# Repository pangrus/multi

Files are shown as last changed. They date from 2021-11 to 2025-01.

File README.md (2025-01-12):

## multi

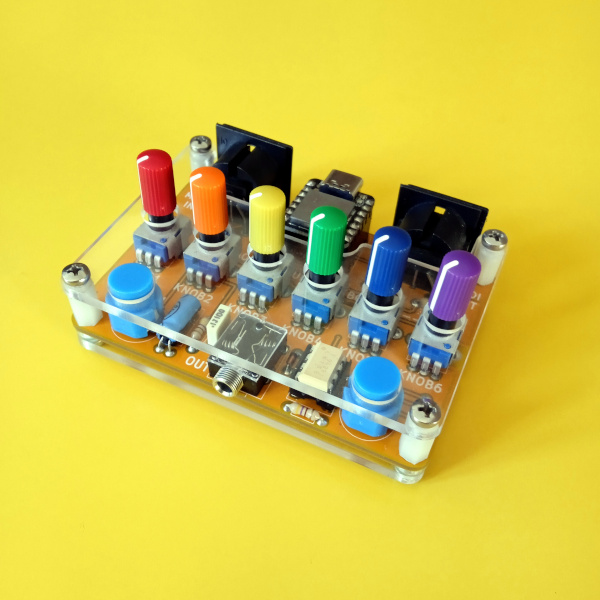
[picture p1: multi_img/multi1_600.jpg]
multi


**What is multi?**  
**multi** is an open hardware circuit board hosting a [Seeeduino XIAO](https://wiki.seeedstudio.com/Seeeduino-XIAO/), 6 pots, 2 pushbuttons, 2 Midi DIN connectors and an audio output.   
The Seeeduino XIAO board carries the powerful ATSAMD21G18A-MU which is a low-power microcontroller and has 14 GPIO PINs, a DAC output and one UART interface. To avoid grounding loops the MIDI input is properly opto-isolated, as required by official specifications.    

**Bend multi to your needs**  
The strong point is that you can program your **multi** as you need, using the Arduino IDE. 
On the MIDI side, possible use includes advanced midi controlling, filtering and remapping as well as algorithmic arpeggiators and aleatoric patch generators. It's also perfect to explore digital synthesis techniques. 

**Sound generation**    
Since the Xiao board has a DAC, **multi** can also be used to produce sounds using the [Mozzi sonification library](https://github.com/sensorium/Mozzi) written by Tim Barrass or accessing directly to the DAC output.
 
**Software**    
 There are already several usable software and the list is constantly expanding:    

- **synth sequencer** three oscillators monophonic synth with embedded sequencer. It receives MIDI clock and note messages
- **drone** it's a six oscillators drone machine   
- **euclidean sequencer** receives midi clock, start/stop on the MIDI DIN input, generates euclidean rhythmes on the MIDI DIN output
- **bytebeat player** allows to play algorithmic music with no instruments and no real oscillators but a math expression that creates an audio output waveform as a function of time, processed 8000 times per second. The expression has six parameters accessible through the **multi** knobs
- **fourier** 3 voices drone generator, each voice is composed by six oscillators tuned on the harmonic overtones, each voice has six lfos
- **cc scrambler** generates random synthesizer patch by spitting out random MIDI CC values (preset fucker)    
- **multimode** keep pressed PB1 and PB2 to choose the mode between: synth sequencer, drone, euclidean sequencer, bytebeat player, fourier and cc scrambler 
- **midi converter** is a USB to 5 DIN bi-directional MIDI converter    
- **midi metronome** takes the MIDI clock from the 5 DIN midi connector and generates a metronome click on the audio output, to allow acoustic musicians to synchronize their performance to an electronic setup     
- **hardware test** if you have choosen the DIY kit you may want to use this software to test your build    
- **fm** a simple fm synth    
- **blink** the ubiquitous blink sketch    

**Compiling and uploading**  
Install the [Arduino IDE](https://www.arduino.cc/en/software), last version tested is 2.3.4.  
Add the Seeeduino Xiao board to your Arduino IDE. Follow the [instructions to get started](https://wiki.seeedstudio.com/Seeeduino-XIAO/#software) on the SeeedStudio wiki and install the version 1.7.8 of the _Seeed SAMD Boards_ package.  
To compile the software, you'll need some libraries, install them from the Arduino IDE Library Manager:  
- [Mozzi](https://github.com/sensorium/Mozzi), tested with version 2.0.1, also install library dependencies
- [Adafruit TinyUSB Library](https://github.com/adafruit/Adafruit_TinyUSB_Arduino), tested with version 0.10.5, no dependencies needed
- [MIDI Library](https://github.com/FortySevenEffects/arduino_midi_library), tested with version 5.0.2  

From the Arduino IDE Tools menu, select _TinyUSB_ as USB stack.

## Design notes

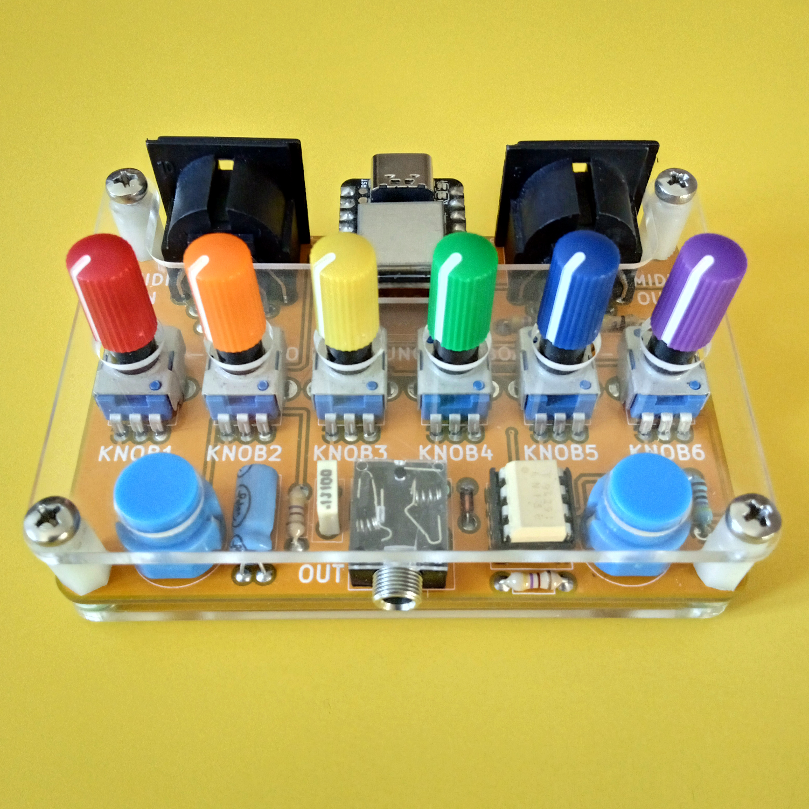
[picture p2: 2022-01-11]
multi_img/multi2.jpg

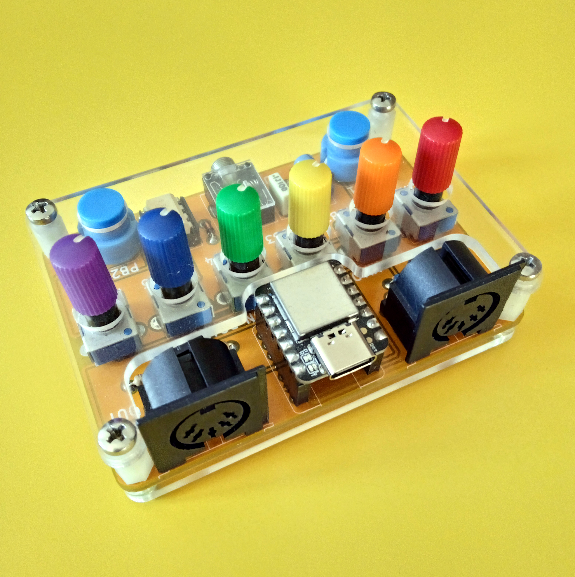
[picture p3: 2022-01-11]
multi_img/multi3.jpg

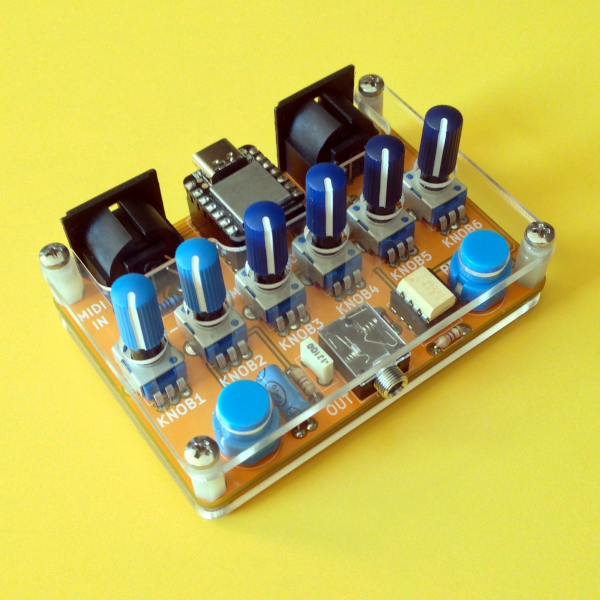
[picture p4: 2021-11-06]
multi_img/multi600.png

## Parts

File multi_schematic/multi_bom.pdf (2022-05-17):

multi - bill of materials

C1 | 100nF | 100V 5% Polyester Capacitor
C2 | 1uF | 50V 105C Radial Electrolytic Capacitor
D1 | 1N4148 | 100V 0.15A standard switching diode
J1 | MIDI IN | 5-pin DIN connector
J2 | MIDI OUT | 5-pin DIN connector
J3 | OUT | 3.5mm Stereo Audio Jack
KNOB 1-6 | 10K | Potentiometer Song Huei RK0904N
PB1,PB2 | Pushbutton | C&K D6R60
R1, R6 | 470 Ohm | Resistor 1/4W
R2, R3 | 47 Ohm | Resistor 1/4W
R4 | 220Ohm | Resistor 1/4W
R5 | 4,7kOhm | Resistor 1/4W
U1 | 6N138 | Low Input Current Optocoupler (8 pin IC socket)
U2 | XIAO | Seeeduino XIAO (7 pin female header x2)

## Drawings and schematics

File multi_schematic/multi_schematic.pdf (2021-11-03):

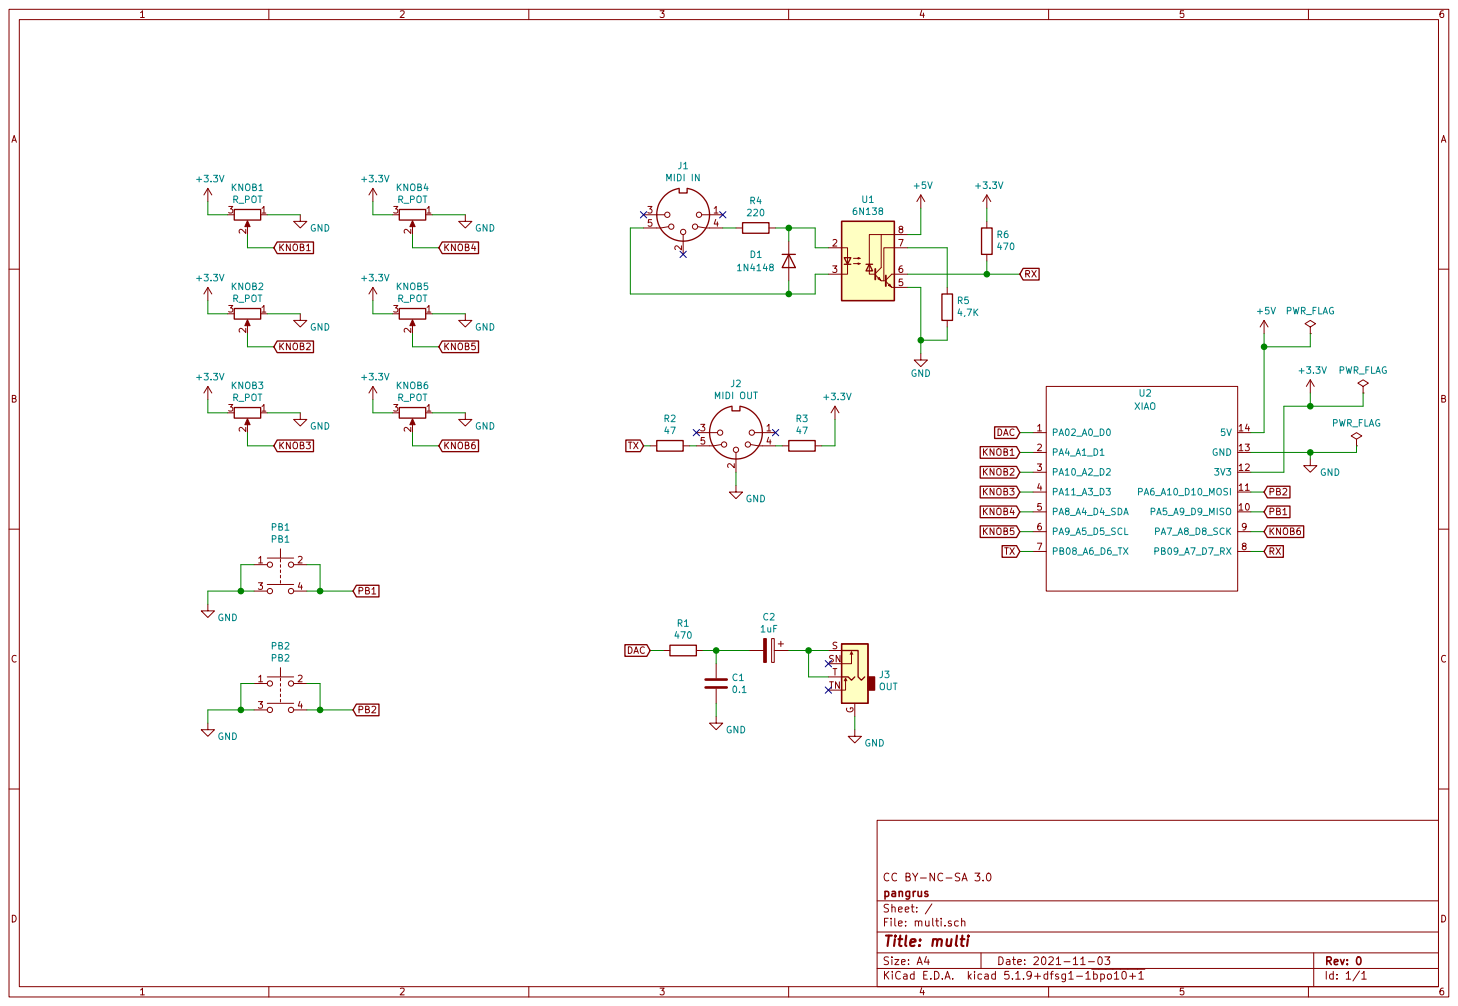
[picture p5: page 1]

Id: 1/1 Title: multi File: multi.sch Sheet: / pangrus CC BY-NC-SA 3.0

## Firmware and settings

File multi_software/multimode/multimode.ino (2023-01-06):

/*
                   _ _   _                     _
   _ __ ___  _   _| | |_(_)_ __ ___   ___   __| | ___
  | '_ ` _ \| | | | | __| | '_ ` _ \ / _ \ / _` |/ _ \
  | | | | | | |_| | | |_| | | | | | | (_) | (_| |  __/
  |_| |_| |_|\__,_|_|\__|_|_| |_| |_|\___/ \__,_|\___|

  multimode v2.2
  CC BY-NC-SA pangrus 2022
  ------------------------

  knobs 1 to 6 are used to select the mode at power up
  knobs 1 to 6 are sending MIDI CC on USB and DIN connectors

  select mode:
  ------------
  set all the knobs fully CCW
  select mode by setting only one knob fully CW (KNOB1 -> mode 1...)
  keep pressed PB1 and PB2 for 4 seconds

  mode 1 : synth sequencer
  ------------------------
  knob1         synth release
  knob2         synth cutoff
  knob3         synth resonance and detune, step advance amount
  knob4         selects sequence
  knob5         transpose sequence
  knob6         sequencer tempo

  mode 2 : drone
  6 oscillators drone generator with 6 lfos
  -----------------------------------------
  knobs 1 to 6  controls the oscillators frequency
  pb1 switches  drone on/off
  pb2 switches  lfos on/off

  mode 3 : euclidean drum sequencer
  ----------------------------
  receives midi clock, start/stop on the MIDI DIN input
  generates euclidean rhythmes on the MIDI DIN output
  knob 1,2,3 selects number of beats to be played
  knob 4,5,6 pattern length
  pb1 randomize pattern 2
  pb2 randomize pattern 3

  mode 4: bytebeat player
  -----------------------
  knobs are affecting expression parameters
  pb1 and pb2 selects different expressions

  mode 5: fourier (3 voices drone generator)
  ------------------------------------------
  each voice is composed by six oscillators tuned on the harmonic overtones
  each voice has six lfos, one for each oscillator level

  KNOB1       controls the first voice main frequency
  KNOB2       controls the second voice main frequency
  KNOB3       controls the third voice main frequency
  PB1         drone on/off
  PB2         lfo mode on/off

  --lfo mode off--
  KNOB4       changes first voice timbre by affecting the overtones level
  KNOB5       changes second voice timbre by affecting the overtones level
  KNOB6       changes third voice timbre by affecting the overtones level

  --lfo mode on--
  KNOB4       changes the six lfos speeds of the first voice
  KNOB5       changes the six lfos speeds of the second voice
  KNOB6       changes the six lfos speeds of the third voice

  mode 6: cc scrambler
  ------------------------------------------
  PB1           scrambles MIDI CC from 0 to 119
  PB2 + KNOB6   change the MIDI channel (from 1 to 10)
  orange led blinks accordingly to the selected MIDI channel
  KNOB1 to KNOB6 sends the assigned MIDI CC
*/

#include <MozziGuts.h>
#include <Oscil.h>
#include <LowPassFilter.h>
#include <mozzi_rand.h>
#include <mozzi_midi.h>
#include <ADSR.h>
#include <Metronome.h>
#include <MIDI.h>
#include <Adafruit_TinyUSB.h>

// wavetables
#include <tables/triangle2048_int8.h>
#include <tables/square_analogue512_int8.h>
#include <tables/sin4096_int8.h>

// mode
byte modeSelect = 1;  //synth mode is the default mode

// MIDI
Adafruit_USBD_MIDI usb_midi;
MIDI_CREATE_INSTANCE(Adafruit_USBD_MIDI, usb_midi, MIDI_USB);
MIDI_CREATE_INSTANCE(HardwareSerial, Serial1, MIDI_DIN);

// MIDI variables
bool isUsbStarted = LOW;
bool isDinStarted = LOW;
bool isMidiNote = LOW;
byte ppq24;
byte usbChannel = 1;
byte dinChannel = 1;

// assign MIDI CC to knobs
#define CC_KNOB1 73     // attack
#define CC_KNOB2 80     // decay
#define CC_KNOB3 64     // sustain
#define CC_KNOB4 72     // release
#define CC_KNOB5 74     // cutoff
#define CC_KNOB6 71     // resonance

// MIDI notes for euclidean sequencer
byte midiNote0 = 60;  // C3
byte midiNote1 = 62;  // D3
byte midiNote2 = 64;  // E3

// knobs are debounced and values are stored
byte actualKnob[] = {0, 0, 0, 0, 0, 0, 0};
byte storedKnob[] = {0, 0, 0, 0, 0, 0, 0};
byte knobThreshold = 3;
byte selectedKnob;

// synth sequencer variables
float bpm;
byte lenght = 16;
int selectedPattern = 0;
int currentStep = 0;
int note;

// euclidean sequencer variables
char euclideanPattern[3][16];
char patternSwap[16];
byte clockCounter = 0;
byte beats1 = 0;
byte beats2 = 0;
byte beats3 = 0;
byte length1 = 16;
byte length2 = 16;
byte length3 = 16;
byte activeStep1 = 0;
byte activeStep2 = 0;
byte activeStep3 = 0;

// pushbuttons management variables
bool pb1Mode;
bool pb2Mode;
bool readPb1;
bool readPb2;
bool pb1State;
bool pb2State;
bool lastPb1State;
bool lastPb2State;
bool isStarted = LOW;
bool normalSequencing = HIGH;
unsigned long lastDebounceTime = 0;
unsigned long debounceDelay = 30000;

// sound generation variables
byte cutoffFrequency;
byte filterResonance;
byte detune;
int releaseTime;
long synthOut;
float mainFrequency;

// drone variables
byte midiNote[6];
byte amplitude1, amplitude2, amplitude3, amplitude4, amplitude5, amplitude6;
int freq[6];
float lfoFreq1, lfoFreq2, lfoFreq3, lfoFreq4, lfoFreq5, lfoFreq6;
long droneOut;

// bytebeat variables
byte parameter1;
byte parameter2;
byte parameter3;
byte parameter4;
byte parameter5;
byte parameter6;
long t = 0;
long bytebeatOut = 0;
bool even;

// fourier variables
byte level[3][6];
int fourierFreq[3];
long fourierOut;

// cc scrambler variables
bool ledState;
byte blinks;
unsigned long currentMillis = 0;
unsigned long previousMillis = 0;
unsigned long blinkTime = 200;
byte midiChannel = 1;
byte controlChangeValue[127];

// reset
const int RESET_TIME  = 3000000;
int lastState = LOW;
int resetState;
unsigned long pressedTime  = 0;
unsigned long releasedTime = 0;
bool isPressing = LOW;
bool isLongDetected = LOW;
long pressDuration;


// patterns are made by midi notes (-1 for pause)
const int pattern[8][16] = {
  {36, 39, 41, 39, 46, 44, 46, 48, 36, 39, 41, 39, 46, 44, 46, 48},   // On The Run
  {41, 36, 51, 36, 48, 36, 36, 48, 36, 48, 36, 48, 46, 36, 48, 36},   // Der Mussolini (The Mussolini)
  {38, 37, 26, 38, 26, 26, 36, 26, 36, 37, 26, 38, 26, 26, 36, 26},   // Verschwende deine Jugend (Waste your youth)
  {55, 48, 48, 50, 50, 43, 50, 43, 55, 48, 48, 50, 50, 43, 50, 43},   // Mein Herz macht Bum (My heart goes boom)
  {49, 37, 37, 52, 49, 37, 37, 46, 49, 37, 37, 52, 49, 37, 37, 46},   // Muskel (Muscle)
  {52, 40, 41, 46, 40, 40, 50, 40, 52, 40, 41, 46, 40, 40, 50, 40},   // Verlieb dich in mich (Fall in love with me)
  {48, 48, 60, 60, 43, 43, 46, 46, 48, 48, 60, 60, 43, 43, 46, 46},   // I feel love
  {55, 40, 40, 54, 40, 40, 55, 40, 40, 54, 40, 40, 55, 40, 54, 40}    // Als wär's das letzte Mal (Like it was the last time)
};

// drone oscillators
Oscil <TRIANGLE2048_NUM_CELLS, AUDIO_RATE> droneOsc1(TRIANGLE2048_DATA);
Oscil <TRIANGLE2048_NUM_CELLS, AUDIO_RATE> droneOsc2(TRIANGLE2048_DATA);
Oscil <TRIANGLE2048_NUM_CELLS, AUDIO_RATE> droneOsc3(TRIANGLE2048_DATA);
Oscil <TRIANGLE2048_NUM_CELLS, AUDIO_RATE> droneOsc4(TRIANGLE2048_DATA);
Oscil <TRIANGLE2048_NUM_CELLS, AUDIO_RATE> droneOsc5(TRIANGLE2048_DATA);
Oscil <TRIANGLE2048_NUM_CELLS, AUDIO_RATE> droneOsc6(TRIANGLE2048_DATA);

// 6 lfos
Oscil<TRIANGLE2048_NUM_CELLS, CONTROL_RATE> lfo1(TRIANGLE2048_DATA);
Oscil<TRIANGLE2048_NUM_CELLS, CONTROL_RATE> lfo2(TRIANGLE2048_DATA);
Oscil<TRIANGLE2048_NUM_CELLS, CONTROL_RATE> lfo3(TRIANGLE2048_DATA);
Oscil<TRIANGLE2048_NUM_CELLS, CONTROL_RATE> lfo4(TRIANGLE2048_DATA);
Oscil<TRIANGLE2048_NUM_CELLS, CONTROL_RATE> lfo5(TRIANGLE2048_DATA);
Oscil<TRIANGLE2048_NUM_CELLS, CONTROL_RATE> lfo6(TRIANGLE2048_DATA);

// 4 oscillators synth
Oscil<SQUARE_ANALOGUE512_NUM_CELLS, AUDIO_RATE> oscillator1(SQUARE_ANALOGUE512_DATA);
Oscil<SQUARE_ANALOGUE512_NUM_CELLS, AUDIO_RATE> oscillator2(SQUARE_ANALOGUE512_DATA);
Oscil<SQUARE_ANALOGUE512_NUM_CELLS, AUDIO_RATE> oscillator3(SQUARE_ANALOGUE512_DATA);
Oscil<SQUARE_ANALOGUE512_NUM_CELLS, AUDIO_RATE> oscillator4(SQUARE_ANALOGUE512_DATA);
ADSR <CONTROL_RATE, AUDIO_RATE> envelope;
LowPassFilter lowPass;

// fourier oscillators and lfos
Oscil < SIN4096_NUM_CELLS, AUDIO_RATE > fourierOsc[3][6];
Oscil < SIN4096_NUM_CELLS, CONTROL_RATE > fourierLfo[3][6];

Metronome seqMetro(120);

void setup() {
  startMozzi();
  analogReadResolution (7);
  analogWriteResolution (10);
  pinMode(9, INPUT_PULLUP);
  pinMode(10, INPUT_PULLUP);
  pinMode(PIN_LED2, OUTPUT);
  pinMode(PIN_LED3, OUTPUT);
  envelope.setTimes(0, 200000, 200000, 1000);
  SerialUSB.begin(115200);
  MIDI_USB.begin(usbChannel);
  MIDI_USB.setHandleStart(usbStart);
  MIDI_USB.setHandleStop(usbStop);
  MIDI_USB.setHandleNoteOn(usbNoteOn);
  MIDI_USB.setHandleNoteOff(usbNoteOff);
  MIDI_USB.setHandleClock(usbClock);
  MIDI_USB.setHandleControlChange(usbHandleCC);
  MIDI_USB.turnThruOff();
  MIDI_DIN.begin(dinChannel);
  MIDI_DIN.setHandleStart(dinStart);
  MIDI_DIN.setHandleStop(dinStop);
  MIDI_DIN.setHandleNoteOn(dinHandleNoteOn);
  MIDI_DIN.setHandleNoteOff(dinHandleNoteOff);
  MIDI_DIN.setHandleClock(dinClock);
  MIDI_DIN.setHandleControlChange(dinHandleCC);
  MIDI_DIN.turnThruOff();
  storedKnob[0] = analogRead(1);
  storedKnob[1] = analogRead(2);
  storedKnob[2] = analogRead(3);
  storedKnob[3] = analogRead(4);
  storedKnob[4] = analogRead(5);
  storedKnob[5] = analogRead(8);
  // lfo frequencies
  lfo1.setFreq(0.0131f);
  lfo2.setFreq(0.0181f);
  lfo3.setFreq(0.0239f);
  lfo4.setFreq(0.0421f);
  lfo5.setFreq(0.0557f);
  lfo6.setFreq(0.0673f);
  // init pattern used for pattern rotation
  for (int i = 0; i < 15; i++) {
    patternSwap[i] = '.';
  }
  for (int j = 0; j < 3; j++) {
    for (int i = 0; i < 6; i++) {
      fourierOsc[j][i].setTable(SIN4096_DATA);
      fourierLfo[j][i].setTable(SIN4096_DATA);
    }
  }
  // mode selection
  if (analogRead(1) > 110) modeSelect = 1;
  if (analogRead(2) > 110) modeSelect = 2;
  if (analogRead(3) > 110) modeSelect = 3;
  if (analogRead(4) > 110) modeSelect = 4;
  if (analogRead(5) > 110) modeSelect = 5;
  if (analogRead(8) > 110) modeSelect = 6;
}

void loop() {
  audioHook();
  MIDI_USB.read();
  MIDI_DIN.read();
}

void updateControl() {
  managePushbuttons();
  manageKnobs();
  switch (modeSelect) {
    case 1:
      synth();
      break;
    case 2:
      drone();
      break;
    case 3:
      euclide();
      break;
    case 4:
      bytebeat();
      break;
    case 5:
      fourier();
      break;
    case 6:
      manageBlinks();
      if (pb1Mode) presetFucker();
      if (pb2Mode) midiChannel = map(storedKnob[5], 0, 120, 1, 10);
      break;
  }
}

// synth
void synth() {
  cutoffFrequency = map (storedKnob[1], 0, 127, 25, 255);
  filterResonance = storedKnob[2] << 1;
  detune = storedKnob[2] >> 4;
  releaseTime = (storedKnob[0] * 3) + 30;
  if (!normalSequencing) {
    cutoffFrequency = rand (25, (char)cutoffFrequency);
    releaseTime = rand(releaseTime, releaseTime * 4);
  }
  envelope.setADLevels(255, 255);
  envelope.update();
  selectedPattern = storedKnob[3] / 16;
  bpm = 100 + (storedKnob[5] * 5);
  seqMetro.setBPM (bpm);
  if (seqMetro.ready() and isStarted) playSynthNote();
}

void playSynthNote() {
  if (!normalSequencing and rand(6) > 4) note = pattern[selectedPattern][currentStep] + map (storedKnob[4], 0, 127, 0, 12) + rand(2) * 12 - rand(2) * 12;
  else note = pattern[selectedPattern][currentStep] + map (storedKnob[4], 0, 127, 0, 12);
  mainFrequency = mtof(note);
  oscillator1.setFreq(mainFrequency);
  oscillator2.setFreq(mainFrequency / 2);
  oscillator3.setFreq(mainFrequency + detune);
  oscillator4.setFreq(mainFrequency - detune);
  lowPass.setCutoffFreqAndResonance(cutoffFrequency , filterResonance);
  envelope.setReleaseTime(releaseTime);
  if (note >= 0) {
    envelope.noteOn();
    envelope.noteOff();
  }
  if (normalSequencing) {
    currentStep++;
    if (currentStep > 15) currentStep = 0;
  }
  else {
    currentStep = currentStep + (9 - storedKnob[2] / 15);
    if (currentStep > 15) currentStep = 9 - storedKnob[2] / 15;
  }
}

// drone
void drone() {
  if (pb2Mode) {
    amplitude1 = map (lfo1.next(), -127, 127, 10, 240);
    amplitude2 = map (lfo2.next(), -127, 127, 10, 240);
    amplitude3 = map (lfo3.next(), -127, 127, 10, 240);
    amplitude4 = map (lfo4.next(), -127, 127, 10, 240);
    amplitude5 = map (lfo5.next(), -127, 127, 10, 240);
    amplitude6 = map (lfo6.next(), -127, 127, 10, 240);
  }
  else {
    amplitude1 = amplitude2 = amplitude3 = amplitude4 = amplitude5 = amplitude6 = 200;
  }
  for (int i = 0; i < 6; i++) {
    midiNote[i] = map (storedKnob[i], 0, 120, 36, 72);
    freq[i] = mtof(midiNote[i]);
  }
  droneOsc1.setFreq(freq[0]);
  droneOsc2.setFreq(freq[1]);
  droneOsc3.setFreq(freq[2]);
  droneOsc4.setFreq(freq[3]);
  droneOsc5.setFreq(freq[4]);
  droneOsc6.setFreq(freq[5]);
}

// euclidean drum sequencer
void euclide() {
  beats1 = map (storedKnob[0], 0, 120, 0, 16);
  beats2 = map (storedKnob[1], 0, 120, 0, 16);
  beats3 = map (storedKnob[2], 0, 120, 0, 16);
  length1 = map (storedKnob[3], 0, 120, 1, 16);
  length2 = map (storedKnob[4], 0, 120, 1, 16);
  length3 = map (storedKnob[5], 0, 120, 1, 16);
  createPattern(0, beats1, length1);
  createPattern(1, beats2, length2);
  createPattern(2, beats3, length3);
  if (pb1Mode) createPattern(1, rand (beats2), 16);
  if (pb2Mode) createPattern(2, rand (beats3), 16);
  rotatePattern(1, 4);
  rotatePattern(2, 2);
}

// bytebeat
void bytebeat() {
  parameter1 = storedKnob[0] >> 3;
  parameter2 = storedKnob[1] >> 3;
  parameter3 = storedKnob[2] >> 3;
  parameter4 = storedKnob[3] >> 3;
  parameter5 = storedKnob[4] >> 3;
  parameter6 = storedKnob[5] >> 3;
}

// fourier
void fourier() {
  for (int j = 0; j < 3; j++) {
    if (!pb2Mode) {
      level[j][0] = storedKnob[j + 3] << 1;
      level[j][1] = storedKnob[j + 3] << 1;
      level[j][2] = 127 - storedKnob[j + 3] << 1;
      level[j][3] = storedKnob[j + 3] << 1;
      level[j][4] = 127 - storedKnob[j + 3] << 1;
      level[j][5] = storedKnob[j + 3] << 1;
    }
    else {
      for (int i = 1; i < 6; i++) {
        fourierLfo[j][i].setFreq((float)storedKnob[j + 3] * (j + 1) / (i * 200));
        level[j][i] = map(fourierLfo[j][i].next(), -127, 127, 3, 247);
      }
    }
    // choose starting chord
    // mtof converts the midi note number to the corresponding frequency
    fourierFreq[0] = mtof((storedKnob[0] >> 2) + 39);
    fourierFreq[1] = mtof((storedKnob[1] >> 2) + 44);
    fourierFreq[2] = mtof((storedKnob[2] >> 2) + 56);
    fourierOsc[j][0].setFreq(fourierFreq[j]);
    for (int i = 1; i < 6; i++) {
      fourierOsc[j][i].setFreq(fourierFreq[j] * (i + 1));
    }
  }
}

void manageBlinks() {
  currentMillis = millis();
  if (currentMillis - previousMillis >= blinkTime) {
    previousMillis = currentMillis;
    if (ledState == LOW) ledState = HIGH;
    else {
      ledState = LOW;
      blinks++;
      if (blinks > midiChannel) {
        blinks = 0;
        ledState = HIGH;
      }
    }
    digitalWrite(LED_BUILTIN, ledState);
  }
}

void presetFucker() {
  for (int i = 0; i < 120; i++) {
    controlChangeValue[i] = random(128);
    MIDI_USB.sendControlChange(i, controlChangeValue[i], midiChannel);
    MIDI_DIN.sendControlChange(i, controlChangeValue[i], midiChannel);
    delay (5);
  }
  SerialUSB.print("Scrambled CC on MIDI channel: ");
  SerialUSB.println(midiChannel);
  pb1Mode = 0;
  digitalWrite (PIN_LED3, !pb1Mode);
}

void manageKnobs() {
  actualKnob[0] = analogRead(1);
  actualKnob[1] = analogRead(2);
  actualKnob[2] = analogRead(3);
  actualKnob[3] = analogRead(4);
  actualKnob[4] = analogRead(5);
  actualKnob[5] = analogRead(8);
  for (int i = 0; i < 6; i++) {
    if (abs(actualKnob[i] - storedKnob[i]) > knobThreshold) {
      // send MIDI CC
      switch (i) {
        case 0:
          MIDI_USB.sendControlChange(CC_KNOB1, actualKnob[i], usbChannel);
          MIDI_DIN.sendControlChange(CC_KNOB1, actualKnob[i], dinChannel);
          break;
        case 1:
          MIDI_USB.sendControlChange(CC_KNOB2, actualKnob[i], usbChannel);
          MIDI_DIN.sendControlChange(CC_KNOB2, actualKnob[i], dinChannel);
          break;
        case 2:
          MIDI_USB.sendControlChange(CC_KNOB3, actualKnob[i], usbChannel);
          MIDI_DIN.sendControlChange(CC_KNOB3, actualKnob[i], dinChannel);
          break;
        case 3:
          MIDI_USB.sendControlChange(CC_KNOB4, actualKnob[i], usbChannel);
          MIDI_DIN.sendControlChange(CC_KNOB4, actualKnob[i], dinChannel);
          break;
        case 4:
          MIDI_USB.sendControlChange(CC_KNOB5, actualKnob[i], usbChannel);
          MIDI_DIN.sendControlChange(CC_KNOB5, actualKnob[i], dinChannel);
          break;
        case 5:
          MIDI_USB.sendControlChange(CC_KNOB6, actualKnob[i], usbChannel);
          MIDI_DIN.sendControlChange(CC_KNOB6, actualKnob[i], dinChannel);
          break;
      }
      storedKnob[i] = actualKnob[i];
      selectedKnob = i + 1;
      SerialUSB.print ("Knob ");
      SerialUSB.print (selectedKnob);
      SerialUSB.print (" value :");
      SerialUSB.println (storedKnob[i]);
    }
  }
}

void managePushbuttons() {
  // pb1
  readPb1 = digitalRead(9);
  if (readPb1 != lastPb1State) {
    lastDebounceTime = mozziMicros();
  }
  if ((mozziMicros() - lastDebounceTime) > debounceDelay) {
    if (readPb1 != pb1State) {
      pb1State = readPb1;
      if (pb1State == LOW) {
        isStarted = !isStarted;
        pb1Mode = !pb1Mode;
        if (modeSelect != 6) {
          if (isStarted) {
            currentStep = 0;
            ppq24 = 0;
            seqMetro.start();
            Serial.println ("Start");
          }
          else {
            envelope.noteOff();
            seqMetro.stop();
            currentStep = 0;
            Serial.println ("Stop");
          }
        }
        digitalWrite (PIN_LED3, !pb1Mode);
      }
    }
  }
  lastPb1State = readPb1;
  // pb2
  readPb2 = digitalRead(10);
  if (readPb2 != lastPb2State) {
    lastDebounceTime = mozziMicros();
  }
  if ((mozziMicros() - lastDebounceTime) > debounceDelay) {
    if (readPb2 != pb2State) {
      pb2State = readPb2;
      if (pb2State == LOW) {
        pb2Mode = !pb2Mode;
        normalSequencing = !normalSequencing;
        digitalWrite (PIN_LED2, !pb2Mode);
        currentStep = 0;
      }
    }
  }
  lastPb2State = readPb2;

  // select mode by keeping pressed PB1 and PB2
  if (!readPb1 and !readPb2) resetState = HIGH;
  else resetState = LOW;
  if ( lastState == LOW && resetState == HIGH ) {
    pressedTime = mozziMicros();
    isPressing = HIGH;
    isLongDetected = LOW;
  } else if (lastState == HIGH && resetState == LOW) {
    isPressing = LOW;
  }
  if ( isPressing == HIGH && isLongDetected == LOW) {
    pressDuration = mozziMicros() - pressedTime;
    if ( pressDuration > RESET_TIME ) {
      Serial.println("Reset");
      if (analogRead(1) > 110) modeSelect = 1;
      if (analogRead(2) > 110) modeSelect = 2;
      if (analogRead(3) > 110) modeSelect = 3;
      if (analogRead(4) > 110) modeSelect = 4;
      if (analogRead(5) > 110) modeSelect = 5;
      if (analogRead(8) > 110) modeSelect = 6;
      pb1Mode = LOW;
      pb2Mode = LOW;
      lastPb1State = LOW;
      lastPb2State = LOW;
      isLongDetected = HIGH;
      digitalWrite (PIN_LED2, HIGH);
      digitalWrite (PIN_LED3, HIGH);
      digitalWrite(LED_BUILTIN, HIGH);
      isUsbStarted = LOW;
      isDinStarted = LOW;
      isMidiNote = LOW;
      ppq24 = 0;
      usbChannel = 1;
      dinChannel = 10;
      normalSequencing = HIGH;
      isStarted = LOW;
    }
  }
  lastState = resetState;
}

// MIDI
void usbStart() {
  if (modeSelect == 1) {
    ppq24 = 0;
    clockCounter = 0;
    currentStep = 0;
    activeStep1 = activeStep2 = activeStep3 = 0;
    isUsbStarted = HIGH;
    SerialUSB.println("USB MIDI Start");
  }
}

void usbStop() {
  if (modeSelect == 1) {
    ppq24 = 0;
    clockCounter == 0;
    currentStep = 0;
    activeStep1 = activeStep2 = activeStep3 = 0;
    isUsbStarted = LOW;
    SerialUSB.println("USB MIDI Stop");
    digitalWrite (PIN_LED3, HIGH);
  }
}

void dinStart() {
  if (modeSelect == 1 or modeSelect == 3) {
    ppq24 = 0;
    clockCounter = 0;
    currentStep = 0;
    activeStep1 = activeStep2 = activeStep3 = 0;
    isDinStarted = HIGH;
    SerialUSB.println("DIN MIDI Start");
  }
}

void dinStop() {
  if (modeSelect == 1 or modeSelect == 3) {
    ppq24 = 0;
    clockCounter = 0;
    currentStep = 0;
    activeStep1 = activeStep2 = activeStep3 = 0;
    isDinStarted = LOW;
    SerialUSB.println("DIN MIDI Stop");
    digitalWrite (LED_BUILTIN, HIGH);
  }
}

void dinClock() {
  if (isDinStarted and modeSelect == 1) {
    if (ppq24 == 0) playSynthNote();
    if (ppq24++ > 4) ppq24 = 0;
    digitalWrite (LED_BUILTIN, ppq24);
  }
  if (isDinStarted and modeSelect == 3) {
    if (clockCounter == 0) {
      if (euclideanPattern[0][activeStep1] == 'x') MIDI_DIN.sendNoteOn (midiNote0, 127, dinChannel);
      if (euclideanPattern[1][activeStep2] == 'x') MIDI_DIN.sendNoteOn (midiNote1, 127, dinChannel);
      if (euclideanPattern[2][activeStep3] == 'x') MIDI_DIN.sendNoteOn (midiNote2, 127, dinChannel);
      activeStep1++;
      activeStep2++;
      activeStep3++;
      if (activeStep1 > length1 - 1) activeStep1 = 0;
      if (activeStep2 > length2 - 1) activeStep2 = 0;
      if (activeStep3 > length3 - 1) activeStep3 = 0;
      MIDI_DIN.sendNoteOff (midiNote0, 0, dinChannel);
      MIDI_DIN.sendNoteOff (midiNote1, 0, dinChannel);
      MIDI_DIN.sendNoteOff (midiNote2, 0, dinChannel);
    }
    if (clockCounter++ > 4) clockCounter = 0;
    digitalWrite (LED_BUILTIN, clockCounter);
  }
}

void usbClock() {
  if (isUsbStarted) {
    if (ppq24 == 0) playSynthNote();
    if (ppq24++ > 4) ppq24 = 0;
    digitalWrite (LED_BUILTIN, ppq24);
  }
}

void usbNoteOn(byte channel, byte note, byte velocity) {
  mainFrequency = mtof(note);
  oscillator1.setFreq(mainFrequency);
  oscillator2.setFreq(mainFrequency / 2);
  oscillator3.setFreq(mainFrequency + detune);
  oscillator4.setFreq(mainFrequency - detune);
  if (velocity > 0) envelope.noteOn();
  else envelope.noteOff();
}
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

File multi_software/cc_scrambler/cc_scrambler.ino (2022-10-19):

/*
                                           _     _
    ___ ___   ___  ___ _ __ __ _ _ __ ___ | |__ | | ___ _ __
   / __/ __| / __|/ __| '__/ _` | '_ ` _ \| '_ \| |/ _ \ '__|
  | (_| (__  \__ \ (__| | | (_| | | | | | | |_) | |  __/ |
   \___\___| |___/\___|_|  \__,_|_| |_| |_|_.__/|_|\___|_|


  cc scrambler - preset fucker v0.4
  ---------------------------------
  PB1           scrambles MIDI CC from 0 to 119
  PB2 + KNOB6   change the MIDI channel (from 1 to 10)
  orange led blinks accordingly to the selected MIDI channel
  KNOB1 to KNOB6 sends the assigned MIDI CC

  CC BY-NC-SA pangrus 2022

  list of MIDI Control Change

  0   00  Bank Select
  1   01  Modulation Wheel or Lever
  2   02  Breath Controller
  3   03  Undefined
  4   04  Foot Controller
  5   05  Portamento Time
  6   06  Data Entry
  7   07  Channel Volume (formerly Main Volume)
  8   08  Balance
  9   09  Undefined
  10  0A  Pan
  11  0B  Expression Controller
  12  0C  Effect Control 1
  13  0D  Effect Control 2
  14  0E  Undefined
  15  0F  Undefined
  16  10  General Purpose Controller 1
  17  11  General Purpose Controller 2
  18  12  General Purpose Controller 3
  19  13  General Purpose Controller 4
  20  14  Undefined
  21  15  Undefined
  22  16  Undefined
  23  17  Undefined
  24  18  Undefined
  25  19  Undefined
  26  1A  Undefined
  27  1B  Undefined
  28  1C  Undefined
  29  1D  Undefined
  30  1E  Undefined
  31  1F  Undefined
  32  20  LSB for Control 0 (Bank Select)
  33  21  LSB for Control 1 (Modulation Wheel or Lever)
  34  22  LSB for Control 2 (Breath Controller)
  35  23  LSB for Control 3 (Undefined)
  36  24  LSB for Control 4 (Foot Controller)
  37  25  LSB for Control 5 (Portamento Time)
  38  26  LSB for Control 6 (Data Entry)
  39  27  LSB for Control 7 (Channel Volume, formerly Main Volume)
  40  28  LSB for Control 8 (Balance)
  41  29  LSB for Control 9 (Undefined)
  42  2A  LSB for Control 10 (Pan)
  43  2B  LSB for Control 11 (Expression Controller)
  44  2C  LSB for Control 12 (Effect control 1)
  45  2D  LSB for Control 13 (Effect control 2)
  46  2E  LSB for Control 14 (Undefined)
  47  2F  LSB for Control 15 (Undefined)
  48  30  LSB for Control 16 (General Purpose Controller 1)
  49  31  LSB for Control 17 (General Purpose Controller 2)
  50  32  LSB for Control 18 (General Purpose Controller 3)
  51  33  LSB for Control 19 (General Purpose Controller 4)
  52  34  LSB for Control 20 (Undefined)
  53  35  LSB for Control 21 (Undefined)
  54  36  LSB for Control 22 (Undefined)
  55  37  LSB for Control 23 (Undefined)
  56  38  LSB for Control 24 (Undefined)
  57  39  LSB for Control 25 (Undefined)
  58  3A  LSB for Control 26 (Undefined)
  59  3B  LSB for Control 27 (Undefined)
  60  3C  LSB for Control 28 (Undefined)
  61  3D  LSB for Control 29 (Undefined)
  62  3E  LSB for Control 30 (Undefined)
  63  3F  LSB for Control 31 (Undefined)
  64  40  Damper Pedal on/off (Sustain)   ≤63 off, ≥64 on
  65  41  Portamento On/Off   ≤63 off, ≥64 on
  66  42  Sostenuto On/Off  ≤63 off, ≥64 on
  67  43  Soft Pedal On/Off   ≤63 off, ≥64 on
  68  44  Legato Footswitch   ≤63 Normal, ≥64 Legato
  69  45  Hold 2  ≤63 off, ≥64 on
  70  46  Sound Controller 1 (default: Sound Variation)
  71  47  Sound Controller 2 (default: Timbre/Harmonic Intens.)
  72  48  Sound Controller 3 (default: Release Time)
  73  49  Sound Controller 4 (default: Attack Time)
  74  4A  Sound Controller 5 (default: Brightness)
  75  4B  Sound Controller 6 (default: Decay Time - see MMA RP-021)
  76  4C  Sound Controller 7 (default: Vibrato Rate - see MMA RP-021)
  77  4D  Sound Controller 8 (default: Vibrato Depth - see MMA RP-021)
  78  4E  Sound Controller 9 (default: Vibrato Delay - see MMA RP-021)
  79  4F  Sound Controller 10 (default undefined - see MMA RP-021)
  80  50  General Purpose Controller 5
  81  51  General Purpose Controller 6
  82  52  General Purpose Controller 7
  83  53  General Purpose Controller 8
  84  54  Portamento Control
  85  55  Undefined
  86  56  Undefined
  87  57  Undefined
  88  58  High Resolution Velocity Prefix
  89  59  Undefined
  90  5A  Undefined
  91  5B  Effects 1 Depth (Reverb Send Level)
  92  5C  Effects 2 Depth (formerly Tremolo Depth)
  93  5D  Effects 3 Depth (Chorus Send Level)
  94  5E  Effects 4 Depth (formerly Celeste [Detune] Depth)
  95  5F  Effects 5 Depth (formerly Phaser Depth)
  96  60  Data Increment (Data Entry +1) (see MMA RP-018)   N/A
  97  61  Data Decrement (Data Entry -1) (see MMA RP-018)   N/A
  98  62  Non-Registered Parameter Number (NRPN) -
  99  63  Non-Registered Parameter Number (NRPN) -
  100 64  Registered Parameter Number (RPN) -  *
  101 65  Registered Parameter Number (RPN) -  *
  102 66  Undefined
  103 67  Undefined
  104 68  Undefined
  105 69  Undefined
  106 6A  Undefined
  107 6B  Undefined
  108 6C  Undefined
  109 6D  Undefined
  110 6E  Undefined
  111 6F  Undefined
  112 70  Undefined
  113 71  Undefined
  114 72  Undefined
  115 73  Undefined
  116 74  Undefined
  117 75  Undefined
  118 76  Undefined
  119 77  Undefined
  120 78  [Channel Mode Message] All Sound Off
  121 79  [Channel Mode Message] Reset All Controllers
  122 7A  [Channel Mode Message] Local Control On/Off
  123 7B  [Channel Mode Message] All Notes Off
  124 7C  [Channel Mode Message] Omni Mode Off (+ all notes off)
  125 7D  [Channel Mode Message] Omni Mode On (+ all notes off)
  126 7E  [Channel Mode Message] Mono Mode On (+ poly off, + all notes off)
*/

#include <MIDI.h>
#include <Adafruit_TinyUSB.h>   // tested with version 0.10.5 

// MIDI
Adafruit_USBD_MIDI usb_midi;
MIDI_CREATE_INSTANCE(Adafruit_USBD_MIDI, usb_midi, MIDI_USB);
MIDI_CREATE_INSTANCE(HardwareSerial, Serial1, MIDI_DIN);
byte usbChannel = 1;
byte dinChannel = 1;

// assign here the MIDI CC to knobs
#define CC_KNOB1 73     // attack
#define CC_KNOB2 80     // decay
#define CC_KNOB3 64     // sustain
#define CC_KNOB4 72     // release
#define CC_KNOB5 74     // cutoff
#define CC_KNOB6 71     // resonance

// CC values
byte controlChangeValue[127];

// active midiChannel;
byte midiChannel = 1;

// ccscrambler blink variables
bool ledState;
byte blinks;
unsigned long currentMillis = 0;
unsigned long previousMillis = 0;
unsigned long blinkTime = 200;

// knobs are debounced and values are stored
int actualKnob[] = {0, 0, 0, 0, 0, 0, 0};
int storedKnob[] = {0, 0, 0, 0, 0, 0, 0};
byte knobThreshold = 3;
byte selectedKnob;

// pushbuttons management variables
bool pb1Mode;
bool pb2Mode;
bool readPb1;
bool readPb2;
bool pb1State;
bool pb2State;
bool lastPb1State;
bool lastPb2State;
unsigned long lastDebounceTime = 0;
unsigned long debounceDelay = 20000;
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
